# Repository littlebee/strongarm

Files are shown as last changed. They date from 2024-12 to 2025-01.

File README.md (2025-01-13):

## This is a work in progress. Will provide updates here and remove this banner when ready for others to use.

Earth date: Dec 26, 2024

The basic code will work to control the arm angles and select arm configs.  Working on Ros2 integration.

# strongarm

The software and docs for my robotic arm.

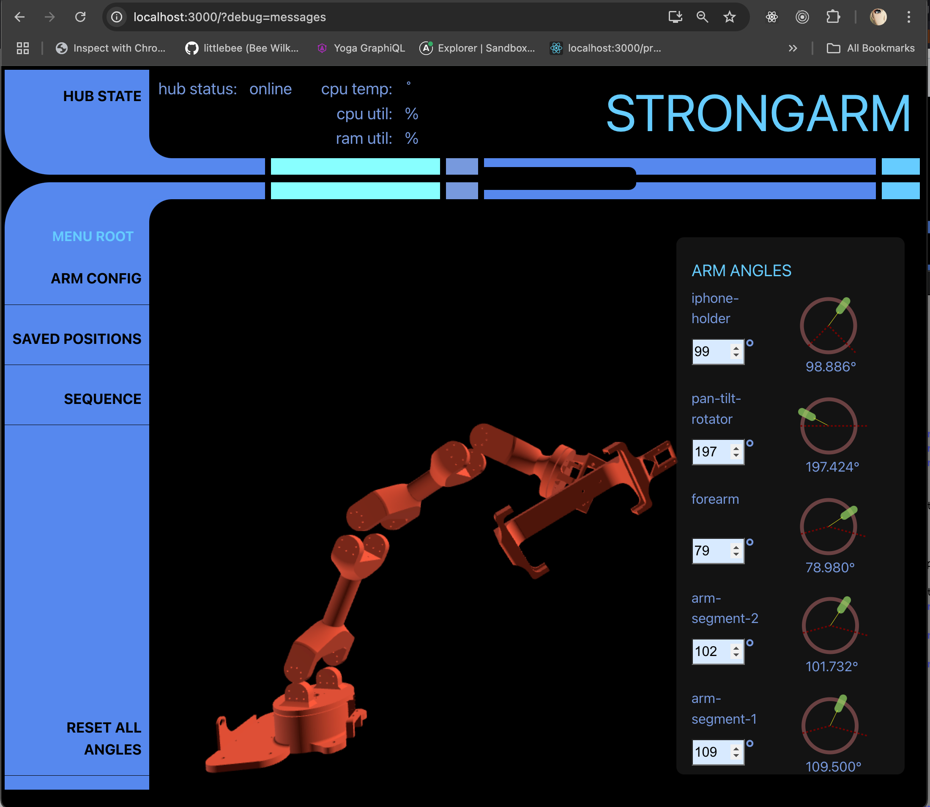
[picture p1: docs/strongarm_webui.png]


## Table of Contents
  - [Physical build parts needed](#physical-build-parts-needed)
    - [3d print the files in `src/webapp/public/arm-parts`](#3d-print-the-files-in-srcwebapppublicarm-parts)
     - [Go shopping](#go-shopping)
  - [Onboard computer and micro controller](#onboard-computer-and-micro-controller)
  - [Getting started](#getting-started)
    - [buy / or build 👆 the arm](#buy--or-build--the-arm)
    - [Clone this repo](#clone-this-repo)
    - [SSH or bust](#ssh-or-bust)
    - [Upload software to on-board SBC](#upload-software-to-on-board-sbc)
    - [Run ./setup.sh on remote SBC](#run-setupsh-on-remote-sbc)
    - [Run the software on the remote](#run-the-software-on-the-remote)
    - [Debugging software problems](#debugging-software-problems)
      - [Are all of the services running on the on-board SBC?](#are-all-of-the-services-running-on-the-on-board-sbc)
      - [Use the webapp](#use-the-webapp)
      - [Inspecting the log files](#inspecting-the-log-files)
      - [Missing packages](#missing-packages)
  - [How it all works](#how-it-all-works)
    - [Central Hub](#central-hub)
  - [Gallery](#gallery)

## Physical build parts needed.

### 3d print the files in `src/webapp_vite/public/arm-parts`
### Go shopping:
Note that I receive no compensation of any form from Amazon, it's just the one place where I know you can find all of these parts.  Please do shop around.  Temu and others have some of these parts for half as much.

| quantity | part needed | cost | link |
| --- | --- | ---- | ---- |
| 1 | 35Kgcm 270&deg; servo for end effector| 28.96 | [amazon](https://www.amazon.com/gp/product/B07S9XZYN2/ref=ppx_yo_dt_b_search_asin_title?ie=UTF8&th=1) |
| 1 | 20Kgcm 270&deg; servo for iphone rotator| 14.99 | [amazon](https://www.amazon.com/gp/product/B0B67YGV66/ref=ppx_yo_dt_b_asin_title_o00_s00?ie=UTF8&th=1) |
| 2 | 60Kgcm 270&deg; dual shaft servo for top arm segments| 30.00 | [amazon](https://www.amazon.com/gp/product/B0C1BXJWMK/ref=ppx_yo_dt_b_search_asin_title?ie=UTF8&th=1) |
| 1 | 150Kgcm 270&deg; dual shaft servo for bottom arm joint| 44.00 | [amazon](https://www.amazon.com/gp/product/B0CP126F77/ref=ppx_yo_dt_b_search_asin_title?ie=UTF8&psc=1) |
| 1 | 60Kgcm 270&deg; single shaft servo for base turntable| 34.89 | [amazon](https://www.amazon.com/gp/product/B08HYX5SX3/ref=ppx_yo_dt_b_search_asin_title?ie=UTF8&psc=1) |
| 36 | M2 16m cap head bolts (for 3 arm join servos) | 6.28 | [amazon](https://www.amazon.com/iexcell-Thread-Socket-Screws-Finish/dp/B0D4JKNJXC/ref=sr_1_3) |
| 36 | M2 washers | 7.99 | [amazon](https://www.amazon.com/HELIFOUNER-Pieces-Washers-Diameter-Thickness/dp/B0B5GYG82X/ref=sr_1_3) |
| 24 | M3 12mm self tapping screws | 5.49 | [amazon](https://www.amazon.com/uxcell-Socket-Tapping-Screws-Carbon/dp/B0D9BDK6ZL/ref=sr_1_3) |
| 4 | M5 20mm button head screws for mounting turn table servo | 8.99 | [amazon](https://www.amazon.com/gp/product/B0BLNMLHYG/ref=ppx_yo_dt_b_search_asin_title) |
| 4 | M5 nuts | 6.99 | [amazon](https://www.amazon.com/Stainless-Self-Locking-Industrial-Construction-Fasteners/dp/B09PF4T3HD/ref=sr_1_3_pp) |
| 1 | 5x14x5mm bearing for iphone tilt arm effector. | 7.69 | [amazon](https://www.amazon.com/gp/product/B075CH4JD6/ref=ppx_yo_dt_b_search_asin_title?ie=UTF8&th=1) |
| 1 | 80x105x4mm thrust bearing for turntable base. | 8.78 | [amazon](https://www.amazon.com/gp/product/B07GC94P6Y/ref=ppx_yo_dt_b_search_asin_title?ie=UTF8&th=1) |
| 3 - 4 ft | 3/4" Spiral wrap | 6.99 | [amazon](https://www.amazon.com/gp/product/B0CT8KFDLY/ref=ppx_yo_dt_b_search_asin_title?ie=UTF8&th=1) |

You will also need to make or buy extension cables for the upper servos.  You can make your own if you have crimpimg tools and skill, wire, and a set of Dupont connectors something like [this set](https://www.amazon.com/gp/product/B07ZK5F8HP/ref=ppx_yo_dt_b_search_asin_title?ie=UTF8&psc=1). Or you can just buy [premade servo extension cables](https://www.amazon.com/TecUnite-Extension-Connectors-Connection-Control/dp/B07C18BXDV/ref=sr_1_4_sspa).

## Onboard computer and micro controller

I have tried be as platform agnostic as I can and the scripts and python code should work with any single board computer and servo controller supported by [Adafruit's servo-kit](https://docs.circuitpython.org/projects/servokit/en/stable/)

I know it works on a Raspberry Pi 4b (4GB), Raspian Bullseye 64, with the [Adeept Motor Hat](https://www.adeept.com/adeept-motor-hat-for-raspberry-pi-smart-robot-car-driver_p0133.html) because I had extra laying around.   The nice thing about the Adeept hat is that it has the power converter that can take any 12 - 60VDC power supply, supply the motors and also supply clean stable 5V power to the Raspberry Pi.

The fixed base model and sbc mounts were designed for the Pi 4/5 and may not fit larger sized SBCs, you will need to rectify that in Tinkercad on your own or house your SBC separately.

## Getting started

### buy / or build 👆 the arm.

For build help, here is the link to a web mockup shared from my fusion 360 disigns that shows the build with servos in place:  https://a360.co/3Phep9W

Connect the servos to the servo controller such that the base turntable servo is channel 0, and then up from there in sequential order.

### Clone this repo
```bash
git clone https://github.com/littlebee/strongarm.git
```

### SSH or bust

You will need to be able to SSH into the onboard computer to upload code.  Ensure that you can successfully log-in,
```bash
ssh myrobotarm.local
```
replace "myrobotarm.local" with the hostname of your onboard computer or its IP address.

Setting up SSH on the SBC will be dependent on the SBC used and variatation of Linux.  For Raspian on Raspberry Pi, here is a [good article.](https://roboticsbackend.com/enable-ssh-on-raspberry-pi-raspbian/)  The raspian image flasher will now alow you to setup SSH from the initial boot full security.

I work on a macbook and use iTerm2 for terminal.  One of the additions I like to make to the standard setup, is to use the same user name on the Pi that I use locally on my mac.  This allows not having to type `ssh raspberry@mybot.local`, because the name is the same just `ssh mybot.local` works.

I also like to add my public key to the `~/.ssh/authorized_keys` file on the remote SBC. This will stop it from prompting you for the password on every SSH command (upload.sh uses rsync which uses ssh).   I made a [gist of the script](https://gist.github.com/littlebee/b285f0b9d219e56fe29b7248440309a5) I use to upload my public key to new boards.

### Upload software to on-board SBC

```bash
./upload.sh myarm.local
```
Upload script uses rsync to upload which only updates changes and is incrementally very fast.  You will use this script often and you intend to make changes to the code.

The upload script will default using your local $USER env.   If you want to use a different user ID on the remote, you will need to specify both the host with user@ prefix and the directory to upload to:
``` bash
./upload.sh pi@myarm.local /home/pi/strongarm
```
If you forget to add the directory when using `user@somehost.local`, you'll likely see a cryptic rsync error in the local terminal.

### Run ./setup.sh on remote SBC
```bash
# ssh onto the machine and cd to the strongarm dirctory.
ssh myarm.local
cd ~/strongarm
./setup.sh
```
You will need to confirm any packages that need to be installed.

Optional:  If you want the robot to start all of the services on boot, you can run these lines from the comments in `./setup.sh` script:
```bash
# rc.local calls start.sh
sudo cp setup/files/etc/rc.local /etc/
sudo chmod +x setup/files/etc/rc.local
```

### Run the software on the remote
```bash
# ssh onto the machine and cd to the strongarm dirctory.
ssh myarm.local
cd ~/strongarm
# run (on remote) startup script
./start.sh
```
That's pretty much it (if everything works, which it may not).  The start script reads the paths of python scripts that start the needed services (see, `services.cfg`).  Each Python script is launched in the background, the PID is saved (for ./stop.sh), and it's error and std output is saved to ~/strongarm/logs.

### Debugging software problems

#### Are all of the services running on the on-board SBC?
```bash
ps -ef | grep python3
```
Compare to `services.cfg` to ensure that all of the service python scripts are running.  Note that just because a service has a running process does not mean it is not failing somewhere.

#### Use the webapp

If the web_server.py and central_hub.py services are running, you might be able to get debug information from the web ui at http://myarm.local.  Click on the "HUB STATE" in the upper left corner and scroll down to `subsystemStatus`

#### Inspecting the log files

When started via `./start.sh`, each subsystem redirects its console ouput (stdout and stderr) to log files in `~/strongarm/logs`.

#### Missing packages

It is likely that the SBC operating system or Python installed onboard the bot may not have a either an OS package  or a Python package that is required.  These types of errors require [Inspecting the log files] to see the error that indicates which package(s) are missing at runtime.

If you find a missing package, please be a sport and add it to `setup.sh` and submit a PR, or just open an issue and let us know if something is missing.

## How it all works

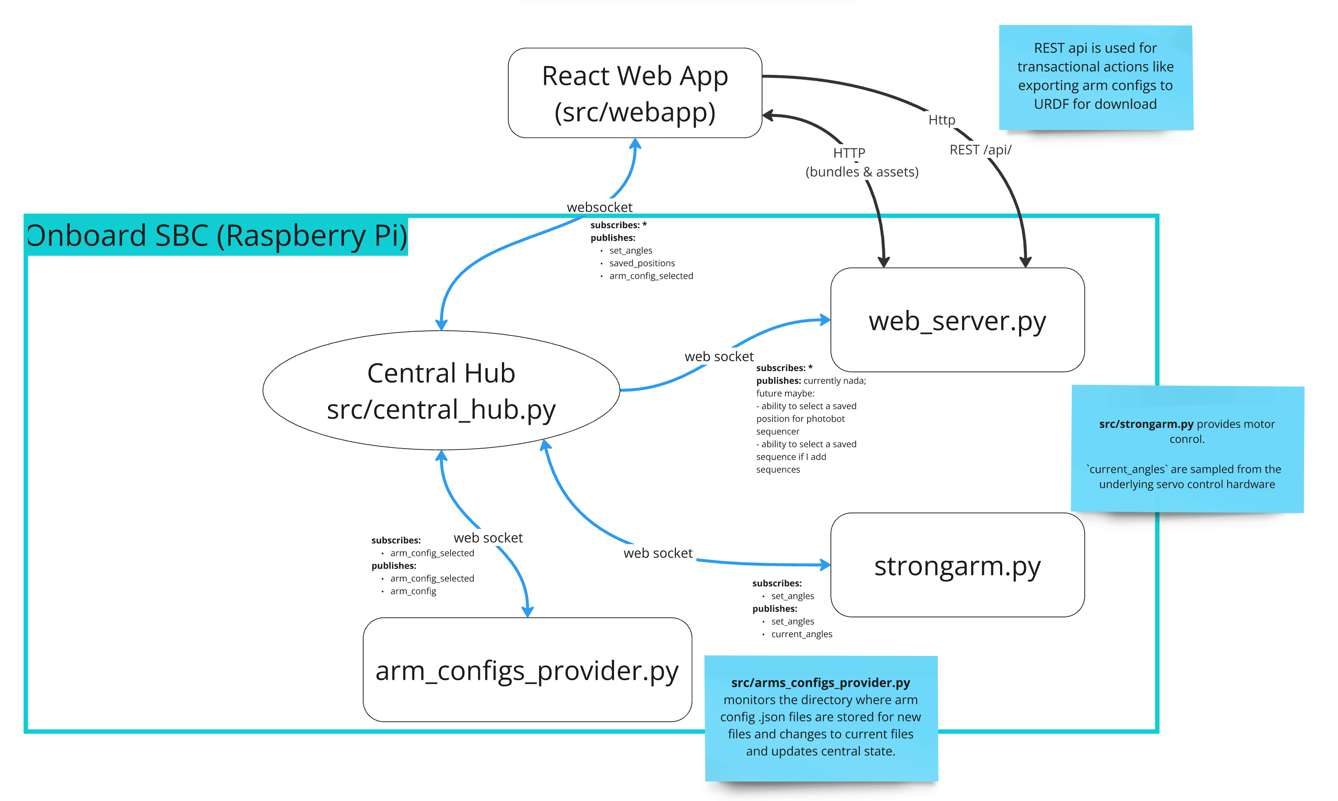
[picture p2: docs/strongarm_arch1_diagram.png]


The backend components are written in Python and the web UI served from the bot's Raspberry PI is in Javascript and React.

The [.stl files](https://github.com/littlebee/strongarm/tree/79ba6f7243c4ec0955e1ae1eabb3a3f58b2f47bb/src/webapp_vite/public/arm-parts) for the 3d parts I designed in Fusion 360 are used along with [three.js](https://threejs.org/) to render the arm in the web UI.  You can 3d print the parts from the .stl files directly from the .stl files in src/webapp_vite/putlic/arm-parts.  For my build pictured, I used Bambu Labs PLA-CF filament, at 0.2mm line height with 50% rectilinier infill.

You can also add different arm configurations, say if you want another 80mm segment or a different effector, you can easily add your own arm config JSON file to the [arm-configs folder](https://github.com/littlebee/strongarm/tree/main/src/webapp_vite/public/arm-configs)

### Central Hub

Central Hub [src/central_hub.py](https://github.com/littlebee/strongarm/blob/main/src/central_hub.py) is an ultra light weight websockets pub/sub service for the other components that provide (publish) and comsume (subscribe) state.    The authorative state of the overall system (like what angles the servos are set) is owned and maintained by central_hub.

The other Python services (processes) use [hub_state.py](https://github.com/littlebee/strongarm/blob/d97ad335952894e5fbf8899775c25bc45a2050fd/src/commons/hub_state.py) and also optionally [messages.py](https://github.com/littlebee/strongarm/blob/main/src/commons/messages.py) [hub_state_monitor.py](https://github.com/littlebee/strongarm/blob/d97ad335952894e5fbf8899775c25bc45a2050fd/src/commons/hub_state_monitor.py) to send and receive messages from central hub over a websocket cient connection and maintain their own local copies of the subscribed keys of the current state.

All data sent over the websocket to and from central_hub is in json and has the format:
```json
{
     "type": "string",
     "data": { ... }
}
```
Where `data` is optional and specific to the type of message. The following messages are supported by `central-hub`:

#### getState

example json:

```json
{
  "type": "getState"
  "data": ["keyName", "keyName"]
}
```
Causes `central-hub` to send the full state via message type = "state" to the requesting client socket.

`data` is optional, if specified, should be array of key names to retrieve. If omitted, all keys (complete state) is sent.

### identity

example json:

```json
{
  "type": "identity",
  "data": "My subsystem name"
}
```

Causes `central-hub` to update `subsystems_stats` key of the shared state and send an "iseeu" message back to client socket with the IP address that it sees the client.

### subscribeState

example json:

```json
{
  "type": "subscribeState",
  "data": ["system_stats", "set_angles"]
}
```

Causes `central-hub` to add the client socket to the subscribers for each of the state keys provided. Client will start receiving "stateUpdate" messages when those keys are changed. The client may also send `"data": "*"` which will subscribe it to all keys like the web UI does.

### updateState

example json:

```json
{
  "type": "updateState",
  "data": {
    "set_angles": [127.4, 66.4, 90, 90, 0],
    "velocity_factor": 1.5
  }
}
```

This message causes `central-hub` merge the receive state and the shared state and send `stateUpdate` messages to any subscribers. Note that the message sent **by clients** (type: "updateState") is a different type than the message **sent to clients** (type: "stateUpdate").

As the example above shows, it is possible to update multiple state keys at once, but most subsystems only ever update one top level key.

The data received must be the **full data for that key**. `central-hub` will replace that top level key with the data received.

### more

For the latest message types and information about the their data structure,  see `messageTypes` [supported in central_hub](https://github.com/littlebee/strongarm/blob/main/src/central_hub.py#L183)

Also look at https://github.com/littlebee/strongarm/blob/main/src/commons/hub_state.py which maintains this application's supported state,  what state keys are persisted, how state is merged from messages.  A few convienience methods for python clients can be found in [src/commons/messages.py](https://github.com/littlebee/strongarm/blob/main/src/commons/messages.py).

On the Javascript side, the webapp has similar components for [hub state](https://github.com/littlebee/strongarm/blob/main/src/webapp/src/util/hubState.js) and [hub messages](https://github.com/littlebee/strongarm/blob/main/src/webapp/src/util/hubMessages.js)

## Gallery

actual build picture 1

actual build picture 2

actual build picture 3

actual build picture 4

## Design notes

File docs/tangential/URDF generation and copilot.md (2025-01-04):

# URDF generation and VsCode Copilot

This is a journal of my experience in using copilot to generate URDF from a mock arm config (the current 4dof + iphone pan tilt effector config).

## Entries

### 20250101.2

Woot! We have a valid URDF based on validations from [here](http://wiki.ros.org/urdf)

### 20250101

Tried giving claude a python file with just a mock_arm_config={...} and the command, "using the XML schema found at https://raw.githubusercontent.com/ros/urdfdom/master/xsd/urdf.xsd, use ElementTree in python 3.13 to convert arm_config to a URDF XML file"

Claude Sonnet 3.5
✅  It generated pretty decent code - although one of the functions a bit long for my tastes
✅  Code generated has zero run time errors
✅  XML generated is formatted and indented for human readability.
❌  XML generated does not cleanly validate with tools used yesterday.  Same two warnings/errors as yesterday.

Gpt 4o
✅  It generated generated good looking, readable codecode
✅  Code generated has zero run time errors
❌  XML generated was not formatted and indented for human readability.  I tried to ask it after the fact to "make the XML generated human readable - the answer was code with RT errors :/
❌  XML generated does not cleanly validate with tools used yesterday.  Same two warnings/errors as yesterday.

### 20241231

It occurred to me from deep in my mind that once dealt with XML also has a schema (duh haha) and there are schema validators.  Let's see what a couple of those online validators have to say about that URDF XML that Claude generated yesterday...

The official schema for URDF is [here](https://github.com/littlebee/strongarm/blob/d13527b5e57598f05cb5dbe802188f13e9146b57/src/commons/to_udrf.py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).  I just pasted that into the schema input of the two different tools along with robot_arm.xml generated by Claude yesterday.

Neither tool liked the comment at the top of ROS's schema file.  Once that was removed, both validators gave the error:

```
cos-all-limited.2: The {max occurs} of an element in an 'all' model group must be 0 or 1. The value 'unbounded' for element 'visual' is invalid.
```

I tried using the following tools:
https://www.liquid-technologies.com/online-xsd-validator
https://www.freeformatter.com/xml-validator-xsd.html

Liquid Technologies tool says the "cos-all-limited" error above is just a warning severity.  It also extraneously complains about `<robot>` not being found in the schema

New approach!!?  I want to try giving Claude the actual schema file from which to generate and specify python 3.13.  Just to see how it does. I then want to repeat the experiment with using gpt-4 in copilot.

### 20241230

In addition to switching to XML, I decided I wanted to see what [Claude 3.5 Sonnet preview](https://www.anthropic.com/news/claude-3-5-sonnet) could do.

So I gave it a python file with just a [mock dictionary](https://github.com/littlebee/strongarm/blob/d13527b5e57598f05cb5dbe802188f13e9146b57/src/commons/to_udrf.py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) of one of strongarm's arm config files, and asked,  "given the specification for URDF, use ElementTree in python to convert arm_config to a URDF XML file."

It generated code that looked about right, but had one run time error because it assumed that the base Python version on my system (3.9) is what I'm actually using to run the code.  I run the code on 3.13 using Anaconda.

I asked it correct for Python 3.13, and the code runs and produces what looks like valid XML (VSCode plugin thinks is kosh).  Only time and testing will tell if it's valid URDF tho.

### 20241227 - 20241228

struggled to get Copilot (gpt 4) and then myself to generate a URDF.

A subject I know little more (+more) than I did - emphasis on "little".  5 separate run time errors I had to ask it to correct.

It occurs to me that, duh, URDF is XML and there are probably great tools in Python to parse and create XML. I may have led Copilot astray as I did ask it to do the task using [urdfpy](https://urdfpy.readthedocs.io/en/latest/).  I think the tool we really need is [ElementTree](https://docs.python.org/3/library/xml.etree.elementtree.html)

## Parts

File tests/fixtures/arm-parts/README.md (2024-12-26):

## arm-parts folder

These are all of the printable models referenced in ../arm-config.    The models are also used for the 3d arm rendered in the webapp.

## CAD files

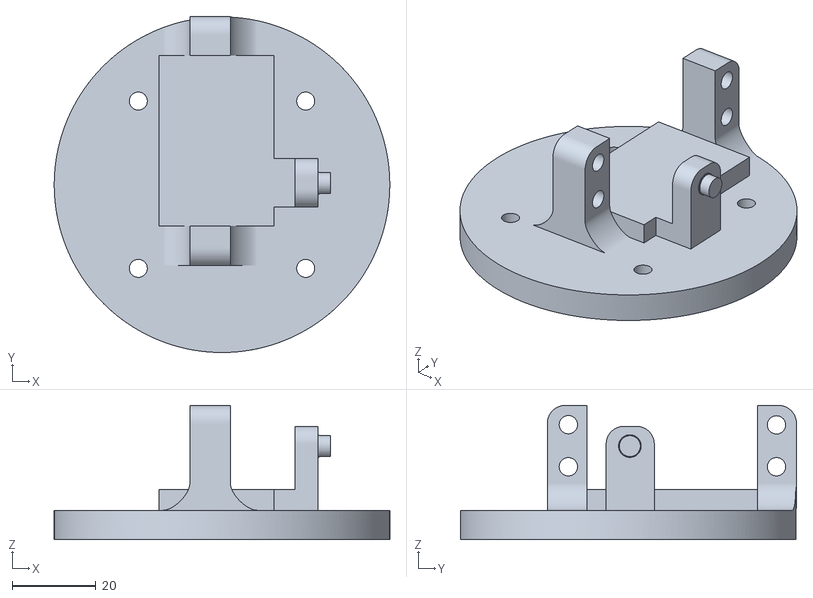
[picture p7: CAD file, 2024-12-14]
tests/fixtures/arm-parts/pan-tilt-base.stl
80.0 x 80.1 x 32.0

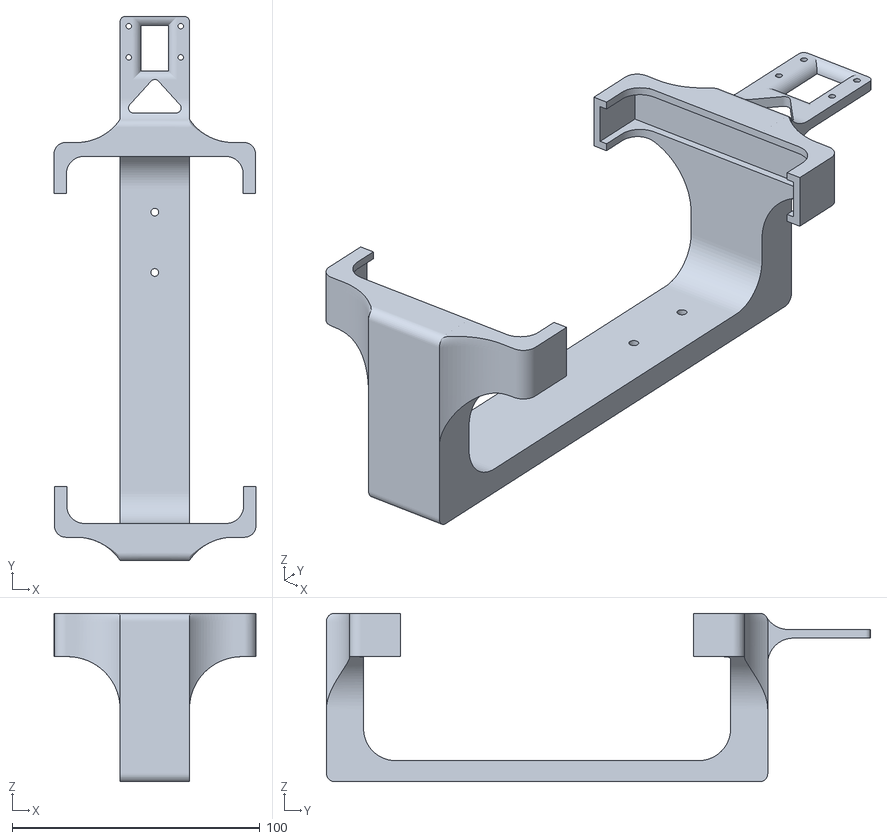
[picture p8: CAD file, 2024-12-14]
tests/fixtures/arm-parts/iphone-holder.stl
81.6 x 219.7 x 68.0

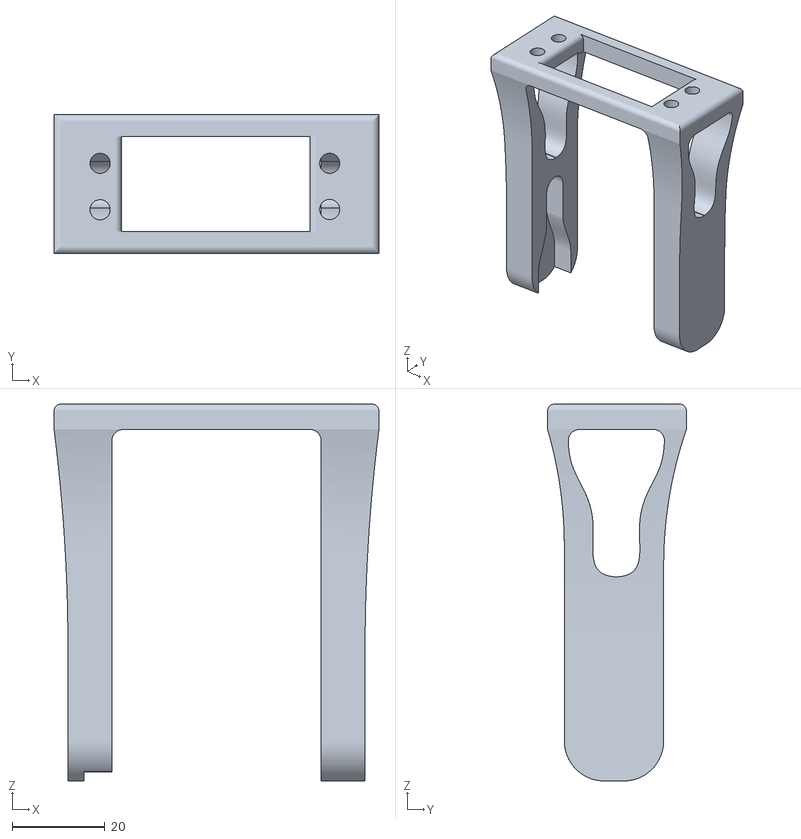
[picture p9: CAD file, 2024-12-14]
tests/fixtures/arm-parts/pan-tilt-rotator.stl
70.2 x 30.0 x 81.5

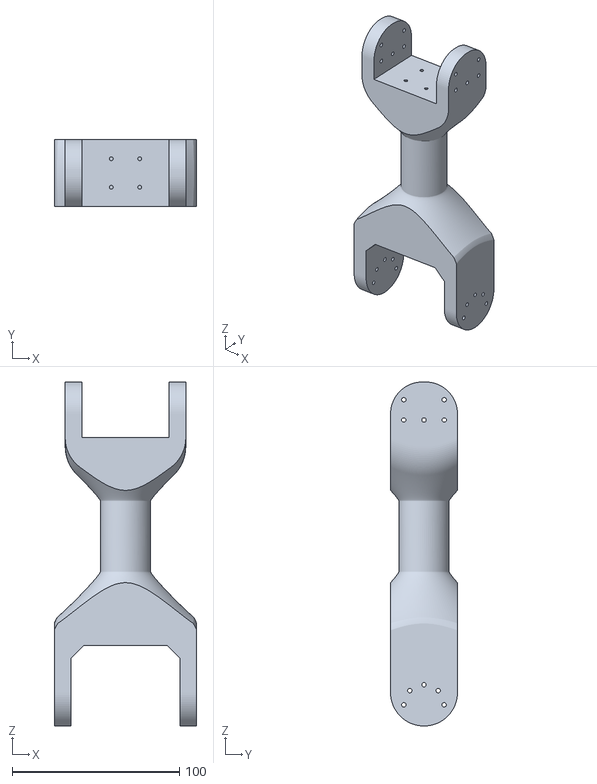
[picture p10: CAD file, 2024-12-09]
tests/fixtures/arm-parts/80mm-arm.stl
85.0 x 40.0 x 205.4

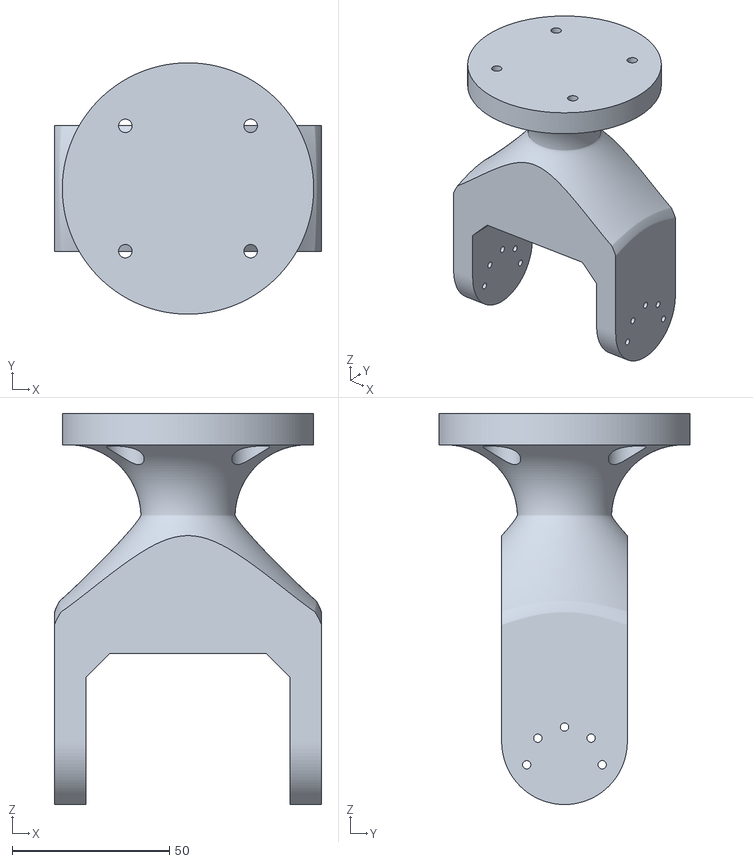
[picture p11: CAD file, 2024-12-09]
tests/fixtures/arm-parts/forearm.stl
85.0 x 80.0 x 124.5

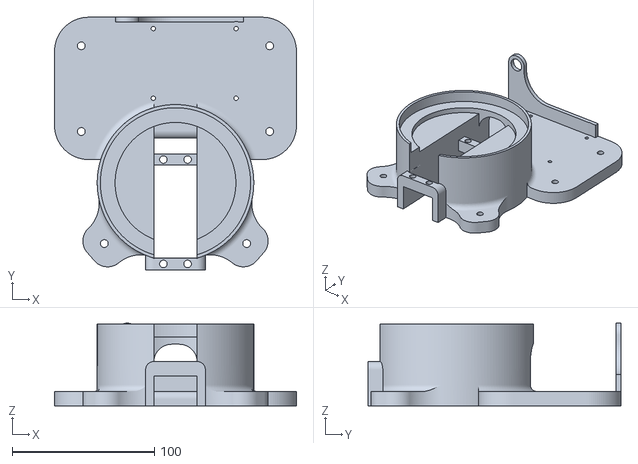
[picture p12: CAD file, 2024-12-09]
tests/fixtures/arm-parts/turntable-bottom.stl
170.0 x 177.4 x 58.2

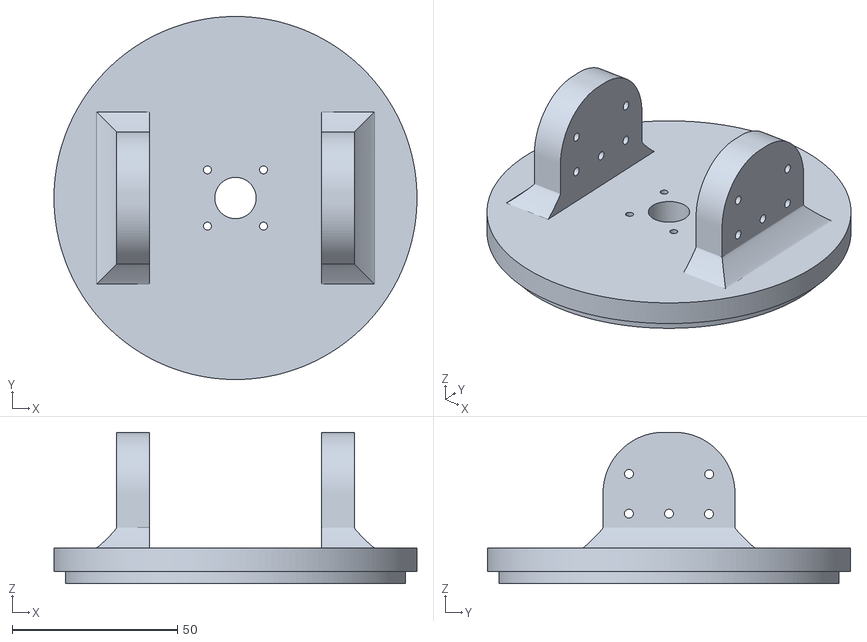
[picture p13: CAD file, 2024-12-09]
tests/fixtures/arm-parts/turntable-top.stl
110.0 x 110.0 x 45.9

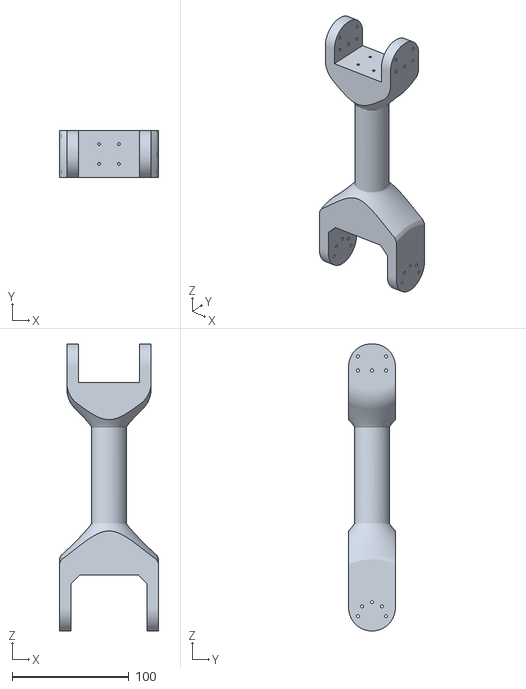
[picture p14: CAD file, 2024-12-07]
tests/fixtures/arm-parts/140mm-arm.stl
85.0 x 40.0 x 245.4

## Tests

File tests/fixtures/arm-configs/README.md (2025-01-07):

The files in this directory each contain a list of parts that comprise the arm. Each part is treated as a child of the part before it meaning that the rotation of a part effects the position of all the parts after it like a segmented arm would.

Each part is a dictionary with the following keys:

- name: (required) a name for display purposes
- file: (required) This is the name of the 3d file that
lives in `src/webapp/public/arm-parts`
- position: (required) This is the position of the part relative to the part below it, in mm
- fixed: (optional) default: false; this part does not move
- rotationAxis: (optional) default: "x";  this is the axis of rotation
- rotationOffset: (optional) default: {x: 0, y: 0, z: 0}; this is the center offset of the rotation axis in mm
- initialRotation: (optional) default: {x: 0, y: 0, z: 0}; this is the initial rotation in degrees
- invertRotation: (optional) default: false.  part rotates counterclockwise
- motorRange: (option) default: 180; this is the max angle supported by the motor
- minAngle: (optional) default: 0; this is the minimum angle that the part can be rotated
- maxAngle: (optional) default: motorRange; this is the maximum angle that the part can be rotated

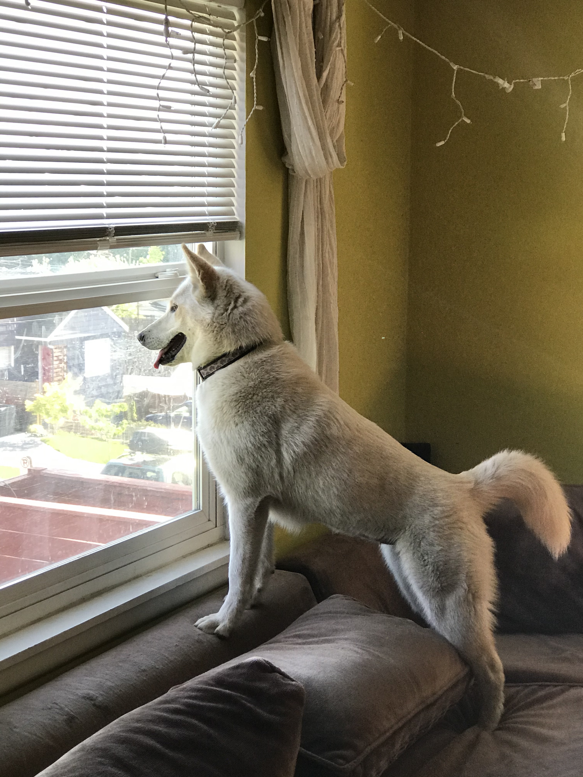
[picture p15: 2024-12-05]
tests/images/daphne-1.jpg

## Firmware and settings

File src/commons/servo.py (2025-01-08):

#!/usr/bin/env python3

import os
import sys
import time
import threading
import traceback

from commons import log, constants as c

if c.STRONGARM_ENV == "production":
    from board import SCL, SDA
    import busio

    # Import the PCA9685 module. Available in the bundle and here:
    #   https://github.com/adafruit/Adafruit_CircuitPython_PCA9685
    from adafruit_pca9685 import PCA9685
    from adafruit_motor import servo as servo_af

    i2c = busio.I2C(SCL, SDA)
    pca = PCA9685(i2c)
    pca.frequency = 50
else:
    log.info(f"commons.Servo running in {c.STRONGARM_ENV} mode.  Using mock servo libs")

    class pca:
        channels = [i for i in range(16)]

    class servo_af:
        class Servo:
            def __init__(self, channel, min_pulse=500, max_pulse=2500):
                self.channel = channel
                self.min_pulse = min_pulse
                self.max_pulse = max_pulse
                self.fraction = 0


# env var to turn on console debug output
DEBUG_MOTORS = os.getenv("DEBUG_MOTORS") or False

# how many deg to turn per step (abs)
STEP_DEGREES = 1
# how long to wait between steps (default; use step_delay setter to change at run time)
DEFAULT_STEP_DELAY = 0.0001

# the precision of the servo motors in degrees
SERVO_PRECISION = 0.5


def limit_angle(angle, min_angle, max_angle):
    limited_angle = angle
    if angle < min_angle:
        limited_angle = min_angle
    elif angle > max_angle:
        limited_angle = max_angle

    return limited_angle


class Servo:
    """
    The servo motors & gearing for shelly-bot's neck ended up being way too
    fast and jerky.  This class uses a thread to slowly step the motor to
    the destination angle.  The step_delay can be adjusted to speed up or slow
    down the movement.  The thread can be paused and resumed.
    """

    def __init__(self, motor_channel, motor_range, min_angle, max_angle):
        self.thread = None  # background thread that steps motor to destination
        self.pause_event = threading.Event()
        self.stopped_event = threading.Event()
        self.force_stop = False
        self._step_delay = DEFAULT_STEP_DELAY

        self.motor_channel = motor_channel
        self.motor_range = motor_range or 180
        self.min_angle = min_angle or 0
        self.max_angle = max_angle or self.motor_range
        self.mid_angle = min_angle + ((max_angle - min_angle) / 2)
        self.destination_angle = self.mid_angle

        self.servo = servo_af.Servo(
            pca.channels[motor_channel], min_pulse=500, max_pulse=2500
        )
        # we need to initialize the servo to the middle of the range
        # to know where it actually is
        log.info(
            f"initializing servo {self.motor_channel} to mid range {self.mid_angle} deg of {self.motor_range} deg motor range"
        )
        self.servo.fraction = self.destination_angle / self.motor_range

        self.thread = threading.Thread(target=self._thread)
        self.thread.start()

    @property
    def current_angle(self):
        try:
            return self.servo.fraction * self.motor_range
        except OSError as error:
            # Was getting intermittent exception from adafruit servo kit
            # originating from i2c_bus.read_i2c_block_data()
            log.error(f"OSError caught in current_angle: {error}\n")
            # just pretend we are at the destination (stop moving) and carry on
            return self.destination_angle

    @property
    def step_delay(self):
        return self._step_delay

    @step_delay.setter
    def step_delay(self, value):
        self._step_delay = value

    def move_to(self, angle):
        new_angle = limit_angle(angle, self.min_angle, self.max_angle)
        if DEBUG_MOTORS:
            log.info(
                f"move_to {self.motor_channel}, {self.current_angle}, {angle}, {self.destination_angle}, {self.min_angle}, {self.max_angle}"
            )

        if abs(self.destination_angle - new_angle) < SERVO_PRECISION:
            if DEBUG_MOTORS:
                log.info(
                    f"{self.current_angle} already at destination angle {self.destination_angle}"
                )
            return

        self.destination_angle = new_angle
        self.stopped_event.clear()
        self.resume()

    def pause(self):
        self.pause_event.clear()

    def resume(self):
        self.pause_event.set()

    def stop_thread(self):
        self.stopped_event.set()
        self.force_stop = True
        # thread could be waiting on pause_event, resume to quit
        self.resume()

    def wait_for_motor_stopped(self):
        if DEBUG_MOTORS:
            log.info(f"waiting on stopped event on channel {self.motor_channel}")
        self.stopped_event.wait()
        if DEBUG_MOTORS:
            log.info(f"after wait: {self.motor_channel} {self.stopped_event.is_set()}")

    def _thread(self):
        log.info(f"Starting servo movement thread. {self.current_angle}")
        self.started_at = time.time()

        if DEBUG_MOTORS:
            log.info(
                f"initializing motor {self.motor_channel} to {self.destination_angle}deg"
            )
        self.servo.fraction = self.destination_angle / self.motor_range
        time.sleep(0.5)
        # need to establish initial position of motor

        # start running
        self.pause_event.set()
        while not self.force_stop:
            self.pause_event.wait()
            direction = 1
            if self.current_angle > self.destination_angle:
                direction = -1

            if DEBUG_MOTORS:
                log.info(
                    f"servo.py thread loop: channel={self.motor_channel} direction={direction} {self.current_angle} {self.destination_angle} "
                )
            if not self._step_move(direction):
                if DEBUG_MOTORS:
                    log.info(f"setting stopped event on channel={self.motor_channel}")
                self.stopped_event.set()
                self.pause_event.clear()

        log.info("servo thread exit on channel={self.motor_channel}")

    def _step_move(self, direction):
        """direction = -1 = left; 1 = right.  returns true if did move"""
        try:
            would_overshoot = self._step_would_overshoot_dest(direction)
            if DEBUG_MOTORS:
                log.info(
                    f"stepping channel={self.motor_channel}, {direction}, {self.current_angle}, {self.destination_angle}, {would_overshoot}"
                )

            if self.current_angle == self.destination_angle:
                return False

            if would_overshoot:
                # get the servo as close to the destination as possible
                self.servo.fraction = self.destination_angle / self.motor_range
                # and then stop the movement loop
                return False

            new_angle = self.current_angle + (STEP_DEGREES * direction)

            self.servo.fraction = new_angle / self.motor_range
            time.sleep(self._step_delay)

            return True
        except Exception:
            log.error(
                f"Exception caught in _step_move for channel={self.motor_channel}: {traceback.format_exc()}"
            )
            return False

    def _step_would_overshoot_dest(self, direction):
        current_angle = self.current_angle
        new_angle = current_angle + STEP_DEGREES * direction
        return (direction == -1 and new_angle < self.destination_angle) or (
            direction == 1 and new_angle > self.destination_angle
        )


if __name__ == "__main__":
    if len(sys.argv) < 2:
        print("usage:  servo.py <channel> (<angle>)")
        exit(1)

    motor_channel = int(sys.argv[1])
    log.info("Ctrl+c to quit")
    test_angles = [
        0,
        180,
    ]
    log.info(f"initializing servo class on motor channel {motor_channel}")
    servo = Servo(motor_channel)

    try:
        if len(sys.argv) > 2:
            new_angle = int(sys.argv[2])
            log.info(f"channel {motor_channel} to {new_angle}deg")
            servo.move_to(new_angle)
            log.info("waiting for motor stopped event")
            servo.wait_for_motor_stopped()
            log.info("got stopped event.")
            servo.stop_thread()
            exit()

        else:
            while True:
                for angle in test_angles:
                    log.info(f"channel {motor_channel} to {angle}deg")
                    servo.move_to(angle)
                    log.info("waiting for motor stopped event")
                    servo.wait_for_motor_stopped()
                    log.info("got stopped event.")
                    # log.info("got stopped event. waiting...")
                    # time.sleep(3)

    except KeyboardInterrupt:
        servo.stop_thread()

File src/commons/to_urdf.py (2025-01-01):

#!/usr/bin/env python3

import xml.etree.ElementTree as ET
from typing import Dict, Any


def create_urdf_from_config(arm_config: Dict[str, Any]) -> ET.Element:
    # Create root robot element
    robot = ET.Element("robot")
    robot.set("name", "strongarm")

    prev_link_name = None

    for part in arm_config["arm_parts"]:
        # Create link element
        link = ET.SubElement(robot, "link")
        link.set("name", part["name"])

        # Add visual element
        visual = ET.SubElement(link, "visual")

        # Add geometry with mesh
        geometry = ET.SubElement(visual, "geometry")
        mesh = ET.SubElement(geometry, "mesh")
        mesh.set("filename", f"package://strongarm/meshes/{part['file']}")

        # Add origin transform
        origin = ET.SubElement(visual, "origin")
        pos = part["position"]
        origin.set("xyz", f"{pos['x']/1000} {pos['y']/1000} {pos['z']/1000}")

        if "initialRotation" in part:
            rot = part["initialRotation"]
            origin.set(
                "rpy",
                f"{rot['x']*3.14159/180} {rot['y']*3.14159/180} {rot['z']*3.14159/180}",
            )

        # Create joint connecting to previous link
        if prev_link_name:
            joint = ET.SubElement(robot, "joint")
            joint.set("name", f"{prev_link_name}_to_{part['name']}")

            if part.get("fixed", False):
                joint.set("type", "fixed")
            else:
                joint.set("type", "revolute")

                # Add joint limits
                limit = ET.SubElement(joint, "limit")
                limit.set("lower", str(part.get("minAngle", -180) * 3.14159 / 180))
                limit.set("upper", str(part.get("maxAngle", 180) * 3.14159 / 180))
                limit.set("effort", "100")
                limit.set("velocity", "1")

            # Set joint parent and child
            parent = ET.SubElement(joint, "parent")
            parent.set("link", prev_link_name)

            child = ET.SubElement(joint, "child")
            child.set("link", part["name"])

            # Add joint origin transform
            j_origin = ET.SubElement(joint, "origin")
            j_origin.set("xyz", f"{pos['x']/1000} {pos['y']/1000} {pos['z']/1000}")

            if "rotationOffset" in part:
                rot = part["rotationOffset"]
                j_origin.set(
                    "rpy",
                    f"{rot['x']*3.14159/180} {rot['y']*3.14159/180} {rot['z']*3.14159/180}",
                )

            # Add rotation axis
            if not part.get("fixed", False):
                axis = ET.SubElement(joint, "axis")
                axis.set("xyz", f"0 0 {-1 if part.get('invertRotation', False) else 1}")

        prev_link_name = part["name"]

    return robot


def save_urdf(arm_config: Dict[str, Any], filename: str):
    robot = create_urdf_from_config(arm_config)
    tree = ET.ElementTree(robot)
    ET.indent(tree, space="  ")
    tree.write(filename, encoding="utf-8", xml_declaration=True)


if __name__ == "__main__":
    mock_arm_config = {
        "description": "4dof arm with iPhone pan and tilt holder",
        "arm_parts": [
            {
                "name": "base",
                "file": "turntable-bottom.stl",
                "position": {"x": 0, "y": 0, "z": 0},
                "initialRotation": {"x": -90, "y": 0, "z": 0},
                "fixed": True,
            },
            {
                "name": "turntable",
                "file": "turntable-top.stl",
                "position": {"x": 0, "y": -27, "z": 50},
                "invertRotation": True,
                "rotationAxis": "z",
            },
            {
                "name": "arm-segment-1",
                "file": "140mm-arm.stl",
                "position": {"x": 0, "y": 0, "z": 150},
                "rotationOffset": {"x": 0, "y": 0, "z": 120},
            },
            {
                "name": "arm-segment-2",
                "file": "80mm-arm.stl",
                "position": {"x": 0, "y": 0, "z": 360},
                "rotationOffset": {"x": 0, "y": 0, "z": 90},
            },
            {
                "name": "arm-segment-3",
                "file": "forearm.stl",
                "position": {"x": 0, "y": 0, "z": 270},
                "initialRotation": {"x": 45, "y": 0, "z": 0},
                "rotationOffset": {"x": 0, "y": 0, "z": 50},
                "minAngle": 13,
            },
            {
                "name": "pan-tilt-base",
                "file": "pan-tilt-base.stl",
                "fixed": True,
                "position": {"x": 0, "y": 0, "z": 130},
                "initialRotation": {"x": 0, "y": 0, "z": 90},
            },
            {
                "name": "pan-tilt-rotator",
                "file": "pan-tilt-rotator.stl",
                "position": {"x": 2, "y": 5, "z": 39},
                "rotationOffset": {"x": 0, "y": 0, "z": 35},
            },
            {
                "name": "iphone-holder",
                "file": "iphone-holder.stl",
                "position": {"x": 0, "y": -20, "z": 120},
                "initialRotation": {"x": 0, "y": 0, "z": 90},
                "invertRotation": True,
                "rotationAxis": "z",
                "rotationOffset": {"x": 0, "y": -20, "z": 0},
            },
        ],
        "filename": "4dof-iphone.json",
        "updated_at": 1735313660.685129,
    }
    # Generate URDF file
    save_urdf(mock_arm_config, "robot_arm.urdf")

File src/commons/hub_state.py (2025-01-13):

import json
import time
from typing import Dict, Any, List
from logging import getLogger

from commons import constants as c

log = getLogger(__name__)

PERSISTED_STATE_FILE = "./persisted_state.json"
TEST_PERSISTED_STATE_INPUT_FILE = "./tests/persisted_state.json"
TEST_PERSISTED_STATE_OUTPUT_FILE = "./tests/persisted_state_out.json"


state: Dict[str, Any] = {
    # provided by central_hub/
    "hub_stats": {"state_updates_recv": 0},
    # last requested angles
    "set_angles": [],
    # actual angles last reported by servos
    "current_angles": [],
    # which subsystems are online and have indentified themselves
    "subsystem_stats": {},
    # array of json file names provided to central hub
    # by arms_config_provider
    "arm_config_files": [],
    # initially by arms_config_provider to last selected, can be changed
    # to any of the arm_configs
    "arm_config_selected": "",
    # currently selected arm config provided by arms_config_provider
    "arm_config": {
        "filename": None,
        "updated_at": None,
        # the arm ports associated with selected arm configuration
        "arm_parts": [],
    },
    # Structure of the objects in the array is consumed and controlled
    # by the UI.
    #
    # See hubState.js for details on the structure of the objects.
    "saved_positions": [],
}

persisted_state_keys: List[str] = [
    "arm_config_selected",
    "saved_positions",
]


# This should only be called by central_hub
def init_persisted_state() -> None:
    file = PERSISTED_STATE_FILE
    if c.STRONGARM_ENV == "test":
        log.info(
            f"Running in test mode, using {TEST_PERSISTED_STATE_INPUT_FILE} persisted state file"
        )
        file = TEST_PERSISTED_STATE_INPUT_FILE

    try:
        with open(file, "r") as f:
            persisted_state = json.load(f)
            for key in persisted_state_keys:
                if key in persisted_state:
                    state[key] = persisted_state[key]
    except FileNotFoundError:
        log.info("No persisted state file found")
    except Exception as e:
        log.error(f"Error loading persisted state: {e}")

    log.info(f"initial state: {state}")


# This should only be called by central_hub
def persist_state() -> None:
    """Persist specified state keys to file."""
    file = PERSISTED_STATE_FILE
    if c.STRONGARM_ENV == "test":
        log.info(
            f"Running in test mode, using {TEST_PERSISTED_STATE_OUTPUT_FILE} file to persist state"
        )
        file = TEST_PERSISTED_STATE_INPUT_FILE

    try:
        persisted_state = {
            key: state[key] for key in persisted_state_keys if key in state
        }
        with open(file, "w") as f:
            json.dump(persisted_state, f, indent=4)
    except (IOError, json.JSONDecodeError) as e:
        log.error(f"Failed to persist state: {e}")


def serialize_state(keysRequested=None) -> str:
    """Serialize current state to JSON string."""

    requestedState = state
    if keysRequested:
        requestedState = {key: state[key] for key in keysRequested if key in state}

    try:
        return json.dumps({"type": "state", "data": requestedState})
    except json.JSONDecodeError as e:
        log.error(f"Failed to serialize state: {e}")
        return json.dumps({"type": "state", "data": {}})


def update_state_from_message_data(message_data: Dict[str, Any]) -> None:
    global state
    """Update state from received message data."""
    for key, data in message_data.items():
        state[key] = data
        state[f"{key}_updated_at"] = time.time()

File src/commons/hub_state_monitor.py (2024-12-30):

"""
This class updates the local copy of the hub state as subscribed keys are changed.

A thread is created to listen for state updates from the central hub.
When a state update is received, the local state is updated and the
state_updated_at timestamp is updated.
"""

import time
import threading
import asyncio
import websockets
import traceback
import json

from commons import constants, messages, log, hub_state


class HubStateMonitor:
    """
    This class updates the process local copy of the hub state as subscribed keys
    are changed.  It starts a thread to listen for state updates from the central
    hub and applies them to the local state via hub_state.update_state_from_message_data.

    This class is a singleton.  Only one instance should be created per process.
    """

    # background thread connects to central_hub and listens for state updates
    thread = None

    # web socket if we are connected, None otherwise
    connected_socket = None

    # these should be provided to the constructor
    identity = "hub_state_monitor"
    # "*" subscribes to all keys or you can pass an array of keys
    subscribed_keys = "*"

    def __init__(self, identity, subscribed_keys):
        HubStateMonitor.identity = identity
        HubStateMonitor.subscribed_keys = subscribed_keys

        if HubStateMonitor.thread is None:
            HubStateMonitor.thread = threading.Thread(target=self._thread)
            HubStateMonitor.thread.start()

    @classmethod
    async def monitor_state(cls):
        while True:
            try:
                log.info(
                    f"hub_state_monitor connecting to hub central at {constants.HUB_URI}"
                )
                async with websockets.connect(constants.HUB_URI) as websocket:
                    cls.connected_socket = websocket
                    await messages.send_identity(websocket, cls.identity)
                    await messages.send_get_state(websocket)
                    await messages.send_subscribe(websocket, cls.subscribed_keys)
                    async for message in websocket:
                        data = json.loads(message)
                        if data.get("type") == "state":
                            message_data = data.get("data")
                            hub_state.update_state_from_message_data(message_data)
                        await asyncio.sleep(0)

            except:
                traceback.print_exc()

            cls.connected_socket = None
            log.info("central_hub socket disconnected.  Reconnecting in 5 sec...")
            time.sleep(5)

    @classmethod
    def _thread(cls):
        log.info("Starting recognition thread.")
        asyncio.run(cls.monitor_state())

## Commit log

2024-12-05 WIP: mostly working pub/sub arch
    [services.cfg]
2024-12-06 add web app for strongarm
    [services.cfg]
2024-12-07 WIP: 3d viewer
    [140mm arm.stl]
2024-12-09 WIP: mostly working 3d display of arm
    [140mm-arm.stl, 80mm-arm.stl, forearm.stl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]
2024-12-09 wip 3d viz: better(?) camera positioning
2024-12-11 WIP: arm angle controls looking cool. time to make them work
2024-12-11 wire up ArmAngleControl to central hub
2024-12-11 round trip set_angles working with servo mock
2024-12-12 WIP: 3d viz almost working. needs... - angles of arm segments are inverted from controls - needs to subtract the initialRotation - wish I had started this from CRA Typescript, instead of perma forkin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
2024-12-13 move arm part definition config into hub state
2024-12-14 build out full arm with iphone effector ++
    change initialRotation arm part attr to vec3
    make controls panel absolute and give 100% width to arm 3d viewer behind it
    enabled threejs orbit controls
    [iphone-holder.stl, pan-tilt-base.stl, pan-tilt-rotator.stl]
2024-12-15 WIP: new microservice for publishing arm configs and subscriber to selected_arm_config
    [services.cfg]
2024-12-16 updating arm-configs files or current file updates hub state
2024-12-16 fix issue with 3d view of arm rotating when arm_parts changes
2024-12-16 more arm 3d viewer cleanup
2024-12-17 add support for touch screens to arm angle input component
    [services.cfg]
2024-12-17 WIP: ugly but working position sidebar and save position dialog
    [services.cfg]
2024-12-18 make persistent state a feature of central_hub
    [services.cfg]
2024-12-19 minimally loveable saved positions feature 🚀
2024-12-21 show saved position as selected if current angles close enough... > > also moved App.css and lcars.css to public and added them to the top of index.html in failed attempt to boost precidence of css m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
2024-12-21 QA pass on full system
    - added support for inverted rotation
    - added ability to edit saved positions without changing angles
    - rc.local should change dir to ~/strongarm scripts etc expect
    - small styling tweaks
    everything is working really well on the 3 segment ar and pointing toward needing one more degree of freedom to rotate the effector, but it always feels like I need one more DOF. Maybe a forth 80mm arm segment? :)
2024-12-23 ui improvements to arm angle controls
2024-12-26 Mass readme additions for how to build and assemble
    [140mm-arm.stl, 80mm-arm.stl, forearm.stl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]
2024-12-27 Update README for arm-configs
2024-12-27 more README. minor bug fix...
    fixed set/current angle of zero showing as 90 deg
2024-12-27 just a little more documentation some borrowed from scatbot...
    I am really just procrastinating on building the URDF file exporter :)
2024-12-27 README: forgot to add bearings to bill of materials
2024-12-28 add api/state REST endpoint for gettting current hub state via http
2024-12-30 add c.ARM_CONFIGS_DIR +++
    + readme and code comment updates
    + expirimental URDF generator, mostly written by Claude. Not sure if it works. trying to get it to load in ROS and Gazebo proving to be challenging. Also learned that Python libs for parsing and producing URDF files is unnecessary. It is XML. Told co-pilot (claude), "given the specification for URDF, use ElementTree in python to convert arm_config to a URDF XML file." It produced one run time error which was caused by assuming I meant Python 3.9 and I am actually using 3.11 in an anaconda env. Produces a valid xml file. Not sure how much work this takes to get other robotics apps to be able to use strongarm.
    [constants.py, hub_state.py, hub_state_monitor.py]
2024-12-31 added script for generating URDF
    for now, just calling from terminal will produce a file called robot_arm.urdf based on testdata
2025-01-01 Woot! We have a valid URDF based on validations from [here](http://wiki.ros.org/urdf)
    I left both Claude and GPT generated code for now to get a permalink for my URDF generation journal. Will delete later.
2025-01-04 move angle validation and clamping to strongarm process + tests
2025-01-05 add tests for arm_configs_provider+++
    - add support for bogus arm_config_selected detection & correct + test
    - correct function naming convention in central_hub.py to be more pythonic
    - reduce central_hup log noise by not freaking out when "no close frame recieved", just close the connection
2025-01-05 WIP: breakout arm parts into their own json files
2025-01-05 finish splitting arm parts config from arm config
2025-01-07 make servos and arm angle control work with 270 deg servos
2025-01-08 onboard manual testing reveals...
    + setting the servo pca frequency is not optional
    + rc.local was not setting STRONGARM_ENV var correctly
    + need more log.info like every good song needs cowbell
    + most importante - stop trying to use python features > 3.9 like `match...case`
    [constants.py, servo.py]
2025-01-10 clean up after copilot...
    - co failed to copy many of the module.css files
    - added hubstate ts definition locally to each component taking it as an arg
    - fixed other
    The web app seems to be working, I only found one thing not working (Arm Config selection) so far. More testing needed
    [140mm-arm.stl, 80mm-arm.stl, forearm.stl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]
2025-01-10 fix changed directories in constants.py
    [constants.py]
2025-01-10 ArmAngleControl switching works again after vite port
2025-01-10 update README and CONTRIBUTING with new directories for arm config and parts
2025-01-10 Arm angle control current angle should show 0.000
    Expected behavior is that, when set to 0 degress, the angle displayed below the circle shows 0.000.
    Mybad. As pennance, I will spend the rest of the day to get either vitest or jest up and working including a test for the above case.
2025-01-12 add startup and teardown of services for vitest tests
    [140mm-arm.stl, 80mm-arm.stl, forearm.stl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]
2025-01-14 Stop redundant persitance of selected arm config
    central hub already persists the selected_arm_config and there is no need for arm_configs_provider to persist it.
2025-01-14 fix arm 3d view sometimes showing last selected arm config and new
    there were several issues
    - animation frame loop was not being canceled between changes
    - loadStl files needs to finish before rendering the scene
